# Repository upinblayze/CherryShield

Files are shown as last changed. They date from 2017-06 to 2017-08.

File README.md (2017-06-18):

# CherryShield

> This project references [this](https://learn.sparkfun.com/tutorials/cherry-mx-switch-breakout-hookup-guide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) guide from [sparkfun](www.sparkfun.com)

This repository is meant to create a prototype using [cherry-mx switches](http://cherryamericas.com/product/mx-series-2/) including necessary concepts such as designing a key matrix and leveraging properties of a general purpose diode.

This project is dependent on [Sparkfun](www.sparkfun.com)'s EAGLE libraries and also OSHPark's DRU file. The EAGLE library is necessary because we use an already made cherry-mx switch footprint.

## Get EAGLE
The EAGLE download can be found [here](https://www.autodesk.com/products EAGLE/free-download). The free version is sufficient in this case
> EAGLE used to be made by CADSOFT USA, but is now under the AutoDesk umbrella.

## Download and apply design rules
We are going to be using [OSHPark's design rules](https://oshpark.com/LaenPCBOrder.dru) since this is the service we are using to make the PCBs

## Clone the repository
For the puposes of simplicity, it is recommended that you clone this repository in your $HOME (root) directory. Input the following command in terminal.

`git clone git@github.com:upinblayze/CherryShield.git`

## Download Sparkfun's EAGLE libraries
They are made for older versions of EAGLE, but they work nonetheless. You may either clone the [repository](https://github.com/sparkfun/SparkFun EAGLE-Libraries) or download the [zip file]( https://github.com/sparkfun/SparkFun EAGLE-Libraries/archive/master.zip)

## Setup EAGLE Directories

1. Options > Directories...
    * To add a paths by placing colons between each file path to where a the desired directory exists
2. To add the Sparkfun EAGLE libraries in the library field, append `:path/to/SparkFun EAGLE-Libraries-master`. In my case, since I have it in the root directory, I would append `:$HOME/SparkFun EAGLE-Libraries-master`
3. Repeat with the Project field. This is meant for if you do not have a project in the EAGLE created folder. I like to keep my git repositories in the root, so I would append `:$HOME/CherryShield` to the project field

> You _may_ want to add the DRU (design rules) directory here, however it may be more intuitive to simply use the design rules check to check against OSHPark design specifications

## Open Project

From here you open the project and click on the schematics. You can view the board also by switching view via the `SCH/BRD` button in the tool bar

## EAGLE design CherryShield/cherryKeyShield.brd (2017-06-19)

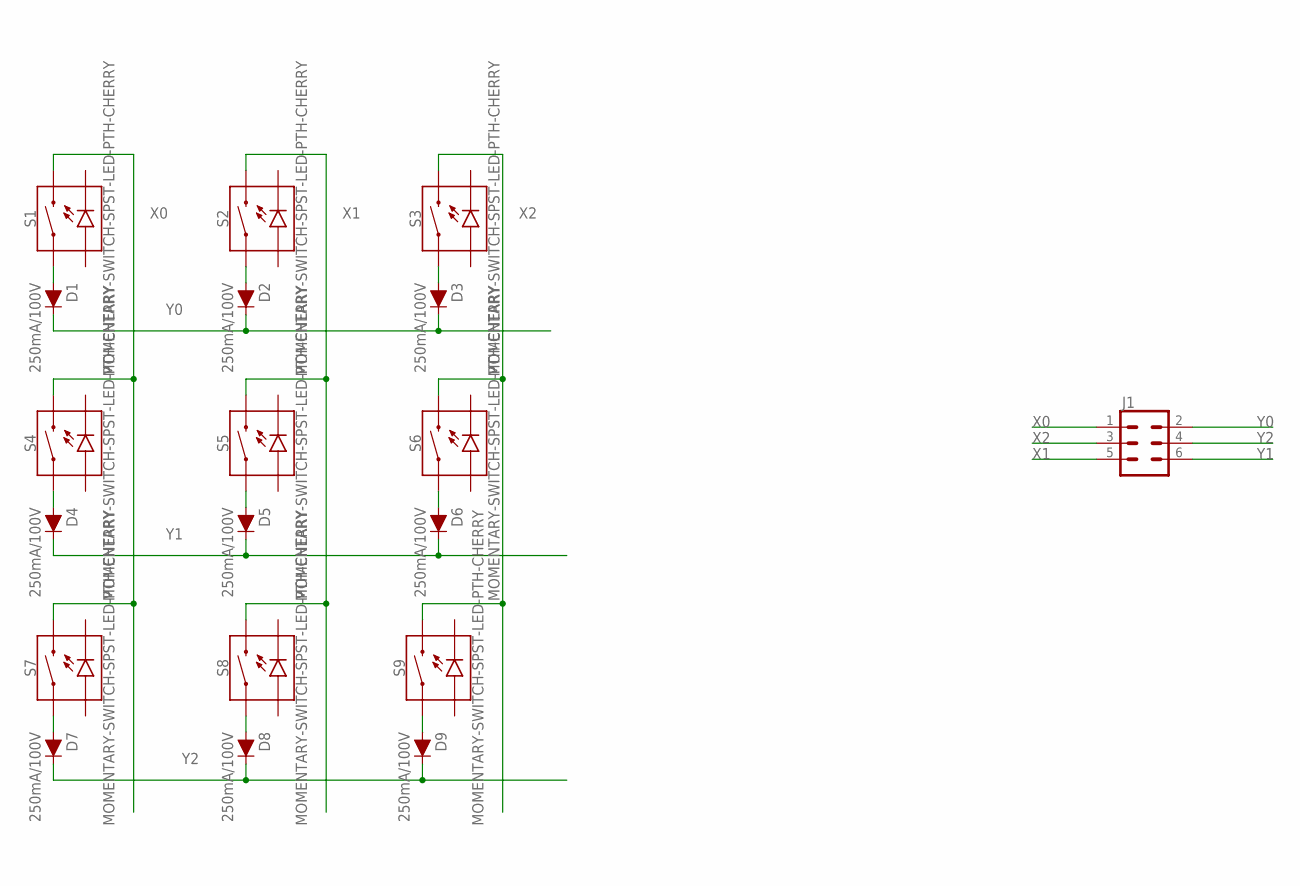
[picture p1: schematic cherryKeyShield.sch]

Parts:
D1, D2, D3, D4, D5, D6, D7, D8, D9: 250mA/100V; SOD-323
J1: CONN_03X22X3_SILK_MALE_PTH; 2X3
S1, S2, S3, S4, S5, S6, S7, S8, S9: MOMENTARY-SWITCH-SPST-LED-PTH-CHERRY; CHERRY-MX-LED

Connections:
unnamed: D5.A, S5.S1 (1)
unnamed: D6.A, S6.S1 (1)
unnamed: D1.A, S1.S1 (1)
unnamed: D2.A, S2.S1 (1)
unnamed: D3.A, S3.S1 (1)
unnamed: D4.A, S4.S1 (1)
unnamed: D8.A, S8.S1 (1)
unnamed: D7.A, S7.S1 (1)
unnamed: D9.A, S9.S1 (1)
X0: J1.1, S1.S2 (2), S4.S2 (2), S7.S2 (2)
X1: J1.5, S2.S2 (2), S5.S2 (2), S8.S2 (2)
X2: J1.3, S3.S2 (2), S6.S2 (2), S9.S2 (2)
Y0: D1.C, D2.C, D3.C, J1.2
Y1: D4.C, D5.C, D6.C, J1.6
Y2: D7.C, D8.C, D9.C, J1.4

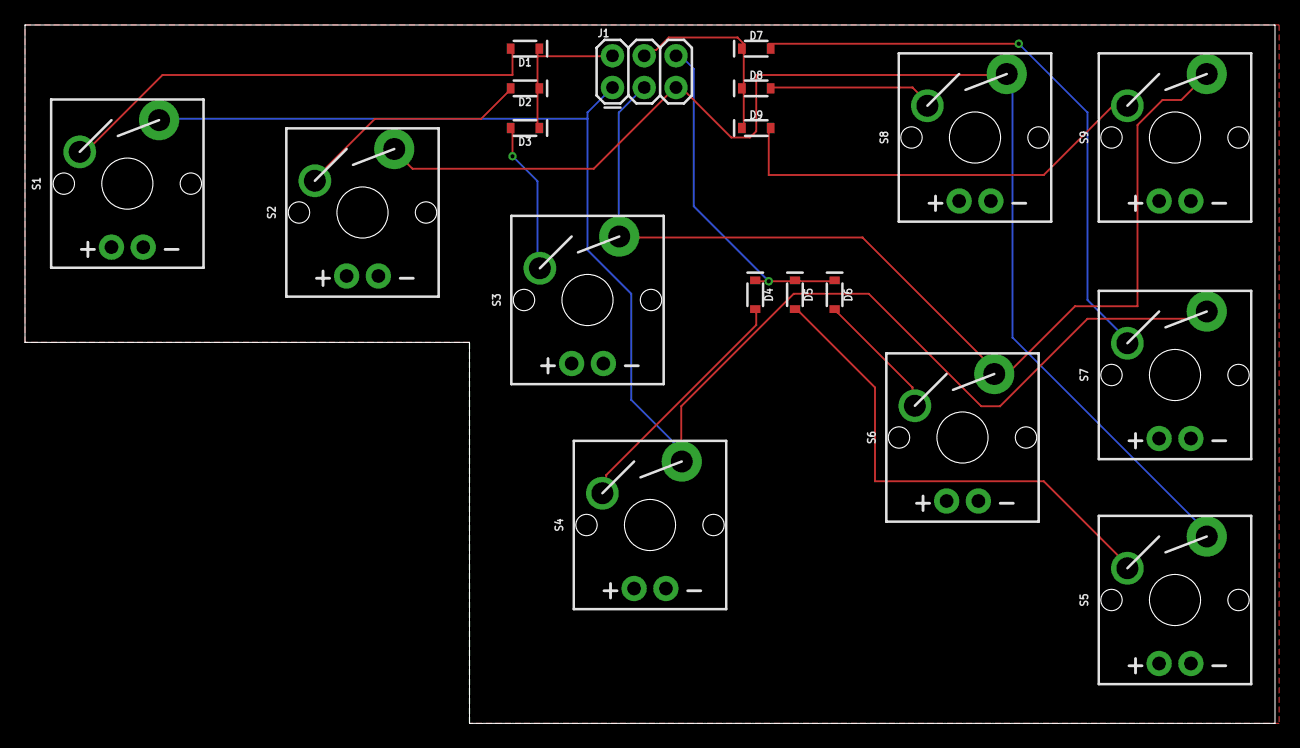
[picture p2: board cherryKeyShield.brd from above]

Board: 2 copper layers, 100.0 x 55.9 mm, 19 parts (0 on the bottom side), 15 nets.

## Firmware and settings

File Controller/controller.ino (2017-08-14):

#include <Key.h>
#include <Keypad.h>
#include <UnoJoy.h>

const byte ROWS = 3;
const byte COLS = 3;

char keys[ROWS][COLS] = {
    {'1', '-', 'D'},
    {'F', '+', 'U'},
    {'R', 'P', 'L'}};

bool pressed[ROWS][COLS] = {
    {false, false, false},
    {false, false, false},
    {false, false, false}};

byte rowPins[ROWS] = {4, 3, 2};
byte colPins[COLS] = {7, 6, 5};

Keypad keypad = Keypad(makeKeymap(keys), rowPins, colPins, ROWS, COLS);

void setup()
{
    setupUnoJoy();
}

void loop()
{

    keyPadEvent();
    dataForController_t controllerData = getControllerData();
    setControllerData(controllerData);
}

void keyPadEvent()
{
    if (keypad.getKeys())
    {
        for (int i = 0; i < LIST_MAX; i++)
        {
            Key k = keypad.key[i];
            switch (k.kchar)
            {
            case 'U':
                setButtonState(k, 1, 2);
                break;
            case 'D':
                setButtonState(k, 0, 2);
                break;
            case 'L':
                setButtonState(k, 2, 2);
                break;
            case 'R':
                setButtonState(k, 2, 0);
                break;
            case 'P':
                setButtonState(k, 2, 1);
                break;
            case 'F':
                setButtonState(k, 1, 0);
                break;
            case '1':
                setButtonState(k, 0, 0);
                break;
            case '+':
                setButtonState(k, 1, 1);
                break;
            case '-':
                setButtonState(k, 0, 1);
                break;
            }
        }
    }
}

void setButtonState(Key k, int row, int column)
{
    switch (k.kstate)
    {
    case PRESSED:
        pressed[row][column] = true;
        break;
    case HOLD:
        pressed[row][column] = true;
        break;
    default:
        pressed[row][column] = false;
    }
}

dataForController_t getControllerData()
{
    dataForController_t controllerData = getBlankDataForController();
    controllerData.dpadUpOn = pressed[1][2];
    controllerData.dpadDownOn = pressed[0][2];
    controllerData.dpadLeftOn = pressed[2][2];
    controllerData.dpadRightOn = pressed[2][0];
    controllerData.crossOn = pressed[0][0];
    controllerData.circleOn = pressed[2][1];
    controllerData.squareOn = pressed[1][0];
    controllerData.startOn = pressed[1][1];
    controllerData.selectOn = pressed[0][1];
    return controllerData;
}

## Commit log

2017-05-08 early stuff
    [cherryKeyShield.brd, cherryKeyShield.sch]
2017-05-17 newer layout
    [cherryKeyShield.brd, cherryKeyShield.sch]
2017-06-19 minimized size for cost
    [cherryKeyShield.brd, cherryKeyShield.sch]
2017-08-14 Working arduino code

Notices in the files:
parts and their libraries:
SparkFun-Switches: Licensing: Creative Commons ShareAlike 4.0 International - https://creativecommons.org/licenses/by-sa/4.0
